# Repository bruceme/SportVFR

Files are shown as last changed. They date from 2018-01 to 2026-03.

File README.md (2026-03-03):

# SportVFR

!CATION! - Continued work in progress

An open-source DIY flight instrument

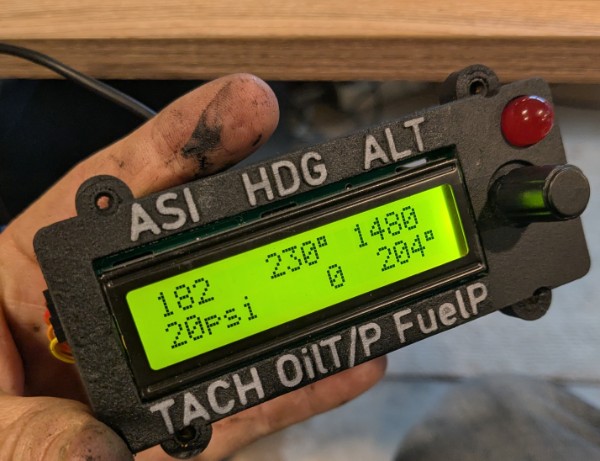
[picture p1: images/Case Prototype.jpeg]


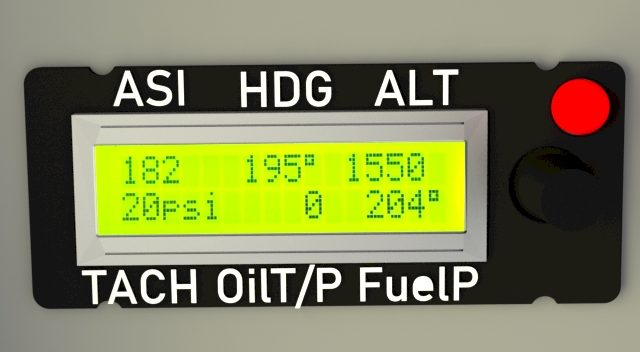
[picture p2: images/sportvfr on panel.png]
SportVFR


Early Prototype (will post updates once v2 is ready, early April 2025)

Sport VFR DIY project

# V0.3 Update (1/21/2026)
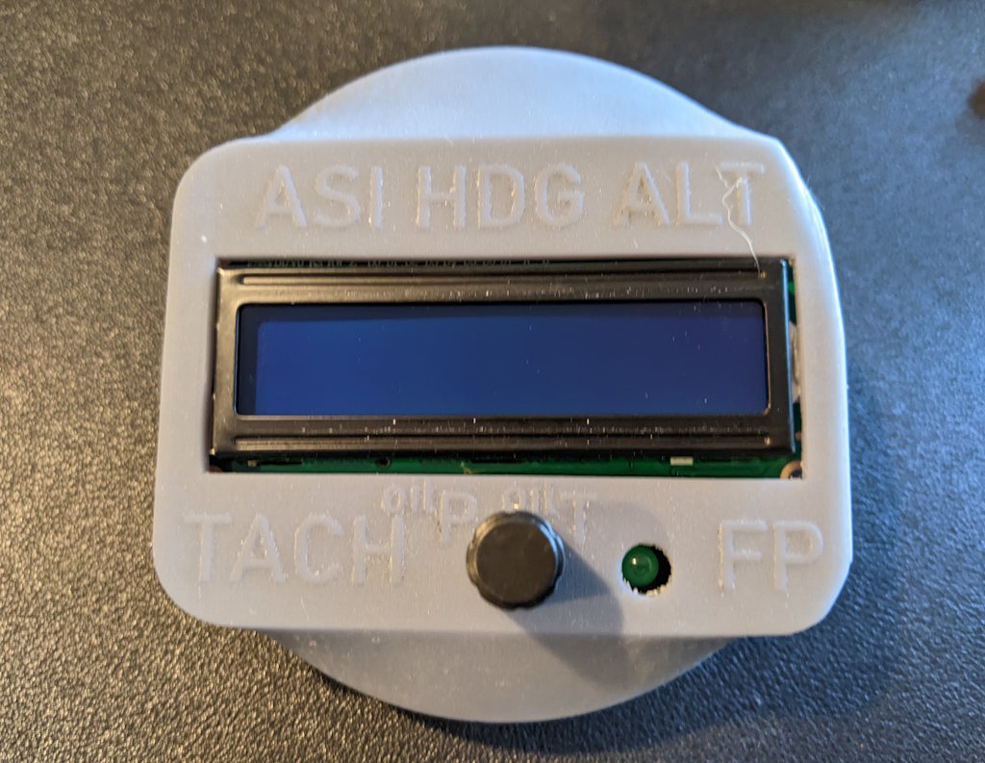
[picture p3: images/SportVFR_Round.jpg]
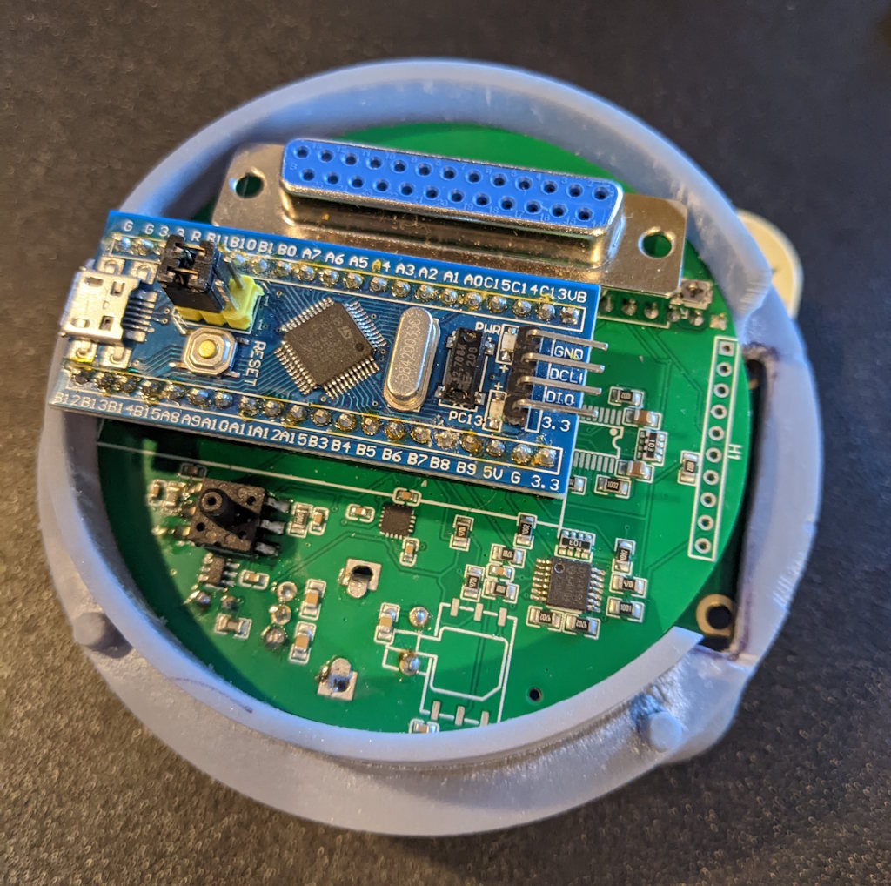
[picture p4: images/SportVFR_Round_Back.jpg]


The most obvious and immediate change is that I switched to the higher speed and higher GPIO pin count on the STM32F103 "Blue Pill".

From feedback, I built a 3-1/8" Round version of the SportVFR, it's built from the identical schematic as the rectangular version. 

I'm preparing to build a flying version, which is an engine monitor only for now.  I will add the airspeed, compass, and altimeter soon, but focusing on the engine sensors and monitoring allows me to finalize them.

I struggled with the configuration so much that I just removed it for now.  It will work for the exact engine sensors I have, if you need to tweak the coefficients for your sensors or use different kinds of sensors, you'll have to change the code for now.  I am thinking about techniques for accommodating various sensors in the hardware and software, but for now, I'm keeping it simple.

Sensors... A constant struggle.  I have settled on a few basic things around sensors.

Fuel Quantity Sensors - Low impedance resistive.  They use a precision op-amp to convert low-current/voltage signals into the analog 0-3.3v signal for the ADC.  I have 4 channels of op-amps.

Oil Temperature - I'm using the Westech oil temp sensor.  It reads 10k-Ohms at 0C, 1.6k Ohms at 39C, 212 Ohms at 100C.  This is easily a low current (0.5ma @ 120C/250F) with a simple voltage divider using a high-precision pull-up resistor.  The code interpolates the logarithmic temperature response curve to give highly accurate temperatures.

Oil Pressure / Fuel Pressure - I use 3-wire pressure sensors; they are much easier to handle and just return voltages from 0.3 - 2.7v using a 3.3v source.  Super simple, also curve-fit-interpolated by the code from measured data.

Outside Air Temp - I used a Dallas one-wire temperature probe.  It's a digital response and highly accurate from -20C - 100C.  I 3d printed a fuse-skin mounting bracket.

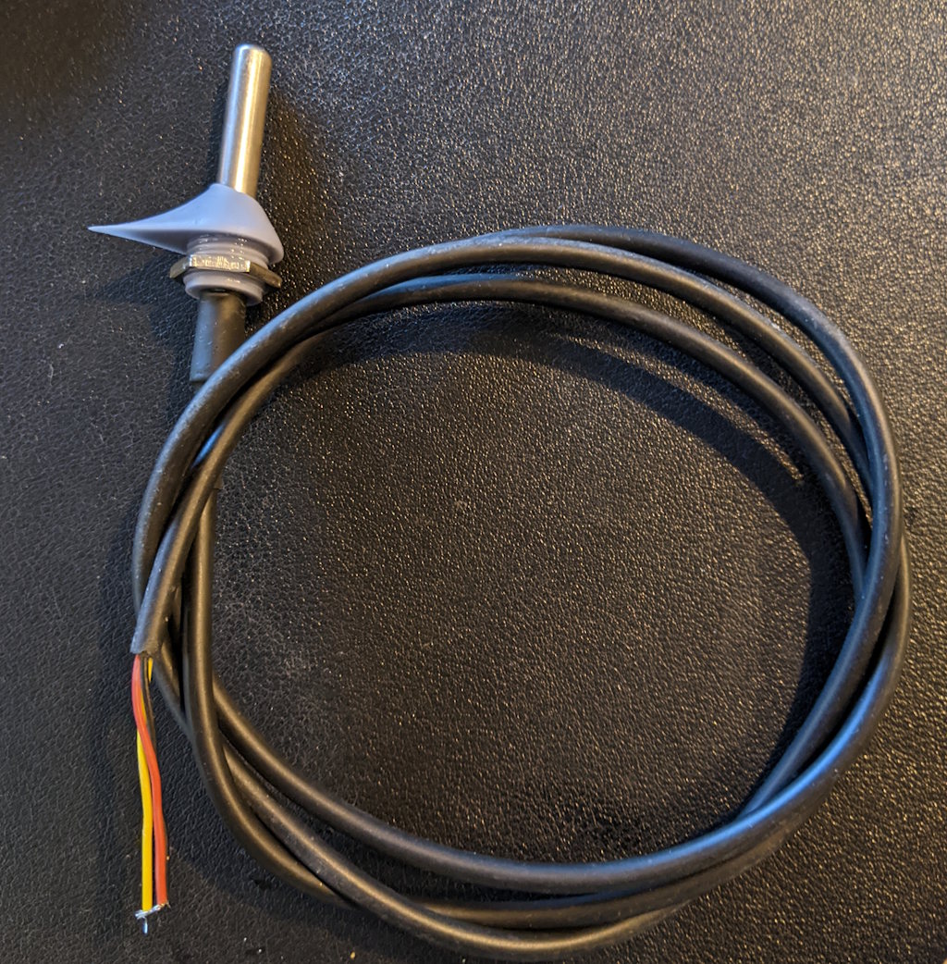
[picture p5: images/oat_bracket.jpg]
Oat Bracket


The Tachometer and Fuel Flow are both pulse count sensors.  This is best done using the built-in hardware clock timers, the code is well documented.  This is not yet tested, and I'm sure there will be tweaks as I get into real-world testing. 

# V0.2 Update (3/31/2025)

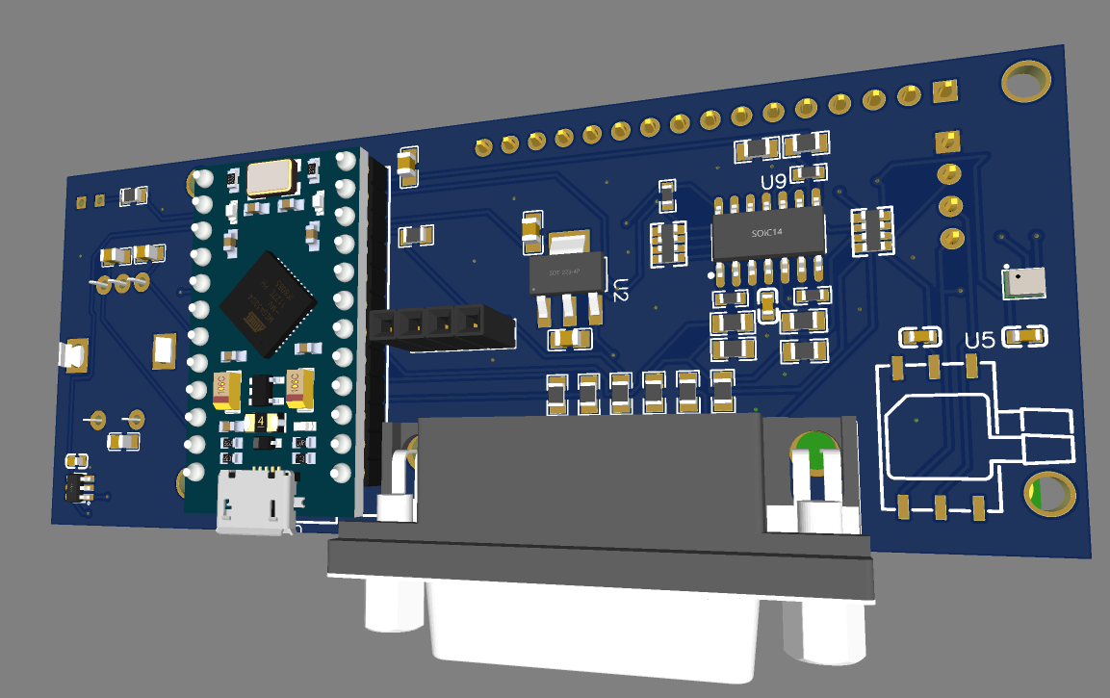
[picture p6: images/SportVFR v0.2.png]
SportVFR0_2

I've been doing a lot of work on this, and I've made several big improvements.

New Wiring Diagram
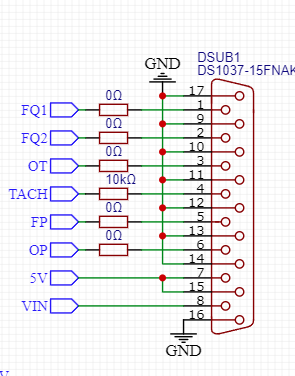
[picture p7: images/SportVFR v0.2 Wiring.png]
SportVFR_0_2_Wiring


1. There's now a DSub-15 pinout with more grounds. unfortunately, couldn't add all the 5V-Out for sensor power needed; there's just one.
1. Using op-amps to measure resistance sensors (OT, FQ1, FQ2), better all around
1. Integrated the magnetometer and absolute pressure sensors into the board design.  This lowers the project cost and makes the BOM smaller and the project simpler to build.
1. I've tested every sensor/instrument and gotten them all working
1. Code changes
 - Lots of simple fixes
 - Sensor-read-skip.  There's 7+ sensors to ready now, It's best to kkin sensor reads each cycle so the slow sensor reads update less frequently than the page display, big performance boost.
 - Created a fuel quantity page

# V0.3 Updates (tbd)

1. DSub25 with more grounds and 5v-Out for sensors
2. Aux1-5 with Aux1 pre-conditioned for low impedence sensors (another fuel quantity, etc)
3. Fuel Flow sensor added

# The Project

## Engine/Aircraft System Data Acquisition
There are only 8 analog input channels. That is limiting, but can support all required inputs;
  
| | Interface | Sensor |
|---|---|---|
| Airspeed | Serial - I2C | ABPMRRV060MG2A3 |
| Altitude | Serial - I2C | GZP6816D |
| Compass | Serial - I2C | TLV493DA1B6HTSA2 |
| Engine RPM | Counter 0-5v | Direct Messure  |
| Oil Temperature | Analog Resistive  | Low-Impedence Amp  |
| Oil Pressure | 0-5v  | 5V Pressure Gauge  |
| Fuel Pressure | 0-5v  | 5V Pressure Gauge  |
| Fuel Quantity, each tank | Analog Resistive  | Low-Impedence Amp |
| Fuel Flow 		 | Counter 0-5v  | BM8563 |
| Tach Hour Meter	 | Uses Tach and time| |

## BOM

### MCU - "Pro Micro atmega32u4"

### Compass and Altitude
  Built into the board

### Air Pressure sensors
[ABPMRRV060MG2A3](https://www.mouser.com/ProductDetail/Honeywell/ABPMRRV060MG2A3?qs=OTrKUuiFdkZ2B8eiLukmLQ%3D%3D)

*Alternatives (will require coding):*
- PX4 Airspeed Module (MS4525DO is the sensor)
- MPXV7002DP - This is a differential analog and may require amplification

### Engine Sensors

- Tach: This is a 2-pulse per rotation 12v signal coming from my Magnetos, it's voltage split to 0-5v.  You can change the number of pulses in the code.
- Oil Temp, Oil Pressure, Fuel Pressure, Fuel Quantity : These are all resistivity sensors with a typical operating range of 0-5kohm.  You can use any sensors that work on your engine.  You will need to calibrate them in the code.
  
### Display
HD44780 -I2C 1602 Character LCD Display

### Input
Rotary Encoder (CYT1100), usually comes with a small knob

### Alert LED
10mm Red LED

## Typical cost break-down (Spring 2025)

| Sport VFR | | |
| --- | --- | --- |
| | Source | Amount  |
| PCB Board | email me | $4.50  |
| Case | thingiverse | $10.00  |
| ProMicro | Jungle | $7.00 |
| Airspeed | Mouser | $35.00  |
| Rotary Encoder | Jungle | $0.56 |
| Alert LED / Resistors | Jungle | $0.10 |
| | | |
| | Sub-Total | $57.16  |
| | | |
| Sample Sensor BOM | | |
| | | |
| Oil Pressure | Jungle | $14.68  |
| Oil Temperature | Jungle | $18.55  |
| Fuel Pressure | Jungle | $23.99  |
| Fuel Quantity x2 | Jungle | $59.98  |
| | | |
| | Sub-Total | $117.20 |
| | | |
| Total. System Cost | | $174.36 |

## The build

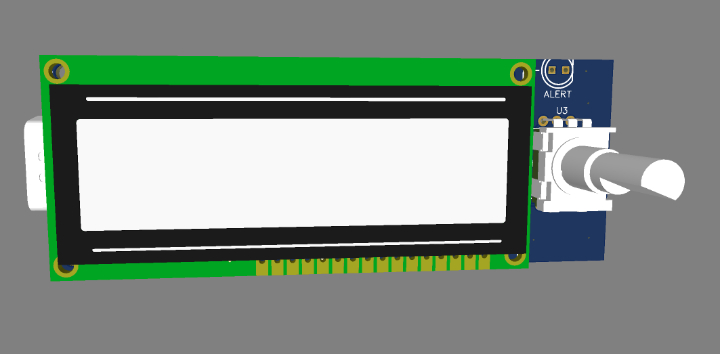
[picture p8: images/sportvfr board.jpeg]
SportVFR Board


The [SportVFR v0.2 Board](scheamtic/SportVFR.0.0.2.zip) contains the Gerber files. These can be fabricated by multiple vendors.  My run of 5 was $20 shipped.  Most components are through-hole, but some are "large" format surface mounts that can be soldered by hand with medium soldering skills.  Installing the DB-9 right-angle connector is preferred so you can remove the display quickly later to work on your panel, but you may directly solder the input wires to the through-holes.

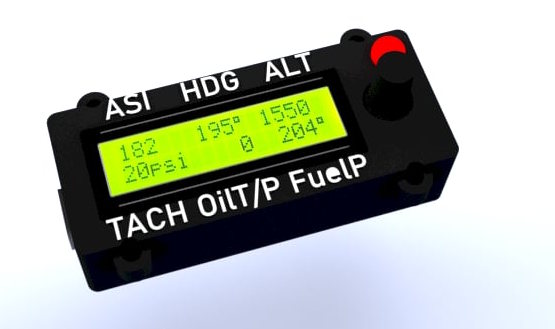
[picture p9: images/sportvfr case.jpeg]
SportVFR Board


For the case, print it yourself or send it out.  It does require 4 6x8mm "threadserts" and M3 screws to mount to the panel.

## Testing and Calibration

!CATION! - Work in progress (see updates coming soon)

Once assembled and connected to sensors you will need to calibrate the system to your sensors.  This is done by compiling to the calibration mode and recording various values at known sensor points.  Please note the calibrations are unitless, you can use whatever units you want, so long as you remember them. Typical US units would be knots, gallons, psi and Fahrenheit... But you could calibrate in kph, liters, mPa and C or any combination so long as the numbers displayed on the screen make sense to you.

Calibration points/ commands are:

You enter compass calibration mode by holding down the encoder button while powering up the unit.  From there you'll be prompted to move the plane in a circle... just follow the prompts.

NOTE: When the in-code varaibles is set to "InCalibrationMode = true" The display is outputing raw values.  The layout is similar to but not identical to the normal display mode in order to show all sensors outputs.  It as as follows:
| Airspeed | Heading  	| Altitude |	 Up/down |
| --- | --- 	| --- |---  |
| Tachometer 		| Oil Temp | Oil Press | Fuel Press | 

How to calibrate various sensors:  This calibration requires you to record values from the unconfigured device and enter them into the code.  You can always re-run these test by setting "InCongig" true and the values will get displayed.

- Airspeed: Read the zero pressure at rest.  Using a hose connected to the top tube of the airspeed sensor, have someone drive you a known speed and record that speed it to that speed.  Enter those values for AirspeedZero and Airspeed60
- Altimeter: Lookup the altitude of your current location.  Set the barometeric pressure to the closest known source and set the altitude in configuraton mode.
- Tachometer: Look up PulsesPerRPM in the code and set that to tachometer source. 
- Oil Temp: Set out a bowl of ice water and get a pot of boiling water, you'll use these test points to calibrate the temperature sensor.  Take the numbers displayed and put them into the code for OilTempMin and OilTempMax
- Oil Pressure & Fuel Pressure: Set the zero pressure at rest.  If your sensors have NPT (nation pipe thread) fittings, they will likely fit directly into a standard compressor hose.  Fill your tank to a known pressure within the range of the sensor and set it to that.  Take the numbers displayed and put them into the code as Oil/Fuel Pressure Min & Max.

# Future thoughts...

## Display or Not Display? That is the question. 

One could easily built an entire dedicated flight information display system (EFIS/ECAM) around this platform.

Or... You could say that any phone or tablet is a perfectly robust flight display system and what if you just focussed on all the data a phone/tablet can't get easily.  Airspeed, Compass, Engine, System sensors, etc.  The project needs to be integrated with a bluetooth transciever (HC-05).  Updates can easily be made to Avare for Android.  At some point compatability with other IMUs would be good so more wide adoption can be considered.

I honestly like both ideas but I lean toward the later as it's simpler and more direct.  Either way, I'd like to leave this project open-ended and not make any decisions that presuppose a display system.  

## IMU Considerations

* Sensors 
	The checked in code uses a HMC5883. The MPU9250 is newer, I would substitute.  This is a  raw output sensor and requires pretty complex 4-dof (quaternion) summing to output useful attitude data.  The altitude pressure sensor are adiquate and usually come with the attitude module.
* Cleanflight / Naze32 upgrade?
	  The Naze32 quad IMU is a nice complete inertia system with tons of great support from the quad copter community.  I have some great success setting it up in aircraft mode and interfacing via serial MultiWii protocol. It output all attitude and altitude data raw with very fast refresh.  It also supports GPS.

## AoA
    A sensitive airspeed sensor could be added for AoA and interface similarly to the airspeed

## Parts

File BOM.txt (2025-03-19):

Bill of Materials for a basic SportVFR board;  Most of these materials you can find with a quick search on the jungle store.

MCU - "Pro Micro atmega32u4"

IMU - GY-652 "10-dof IMU" consists of...
  MPU9250 - 3-Acc + 3-Gyro + 3-Mag  NOTE: Code uses HMC5883. MPU9250 is newer, I would substitute.
  BMP180  - Altimeter
  
Air Pressure sensors (Airspeed / AoA)
    ABPMRRV060MG2A3 - https://www.mouser.com/ProductDetail/Honeywell/ABPMRRV060MG2A3?qs=OTrKUuiFdkZ2B8eiLukmLQ%3D%3D
  
  Alternatives (will require re-coding): 
	PX4 Airspeed Module (MS4525DO is the sensor)
	MPXV7002DP - This is differential analog

Engine Sensors
	Tach - This is a 2-pulse per rotation 12v signal coming from my Magnetos, it's voltage split to 0-5v
	
	Oil Temp, Oil Pressure, Fuel Pressure, Fuel Quantity - These are all resistivity sensors with a typical operating range of 0-5kohm.  You can use any sensors that work on your engine.  You will need to calibrate them in the code.
  
Display - HD44780 - I2C 1602 Character LCD Display

Input - Rotary Encoder (CYT1100), usually comes with a small knob

Alert LED - 10mm Red LED

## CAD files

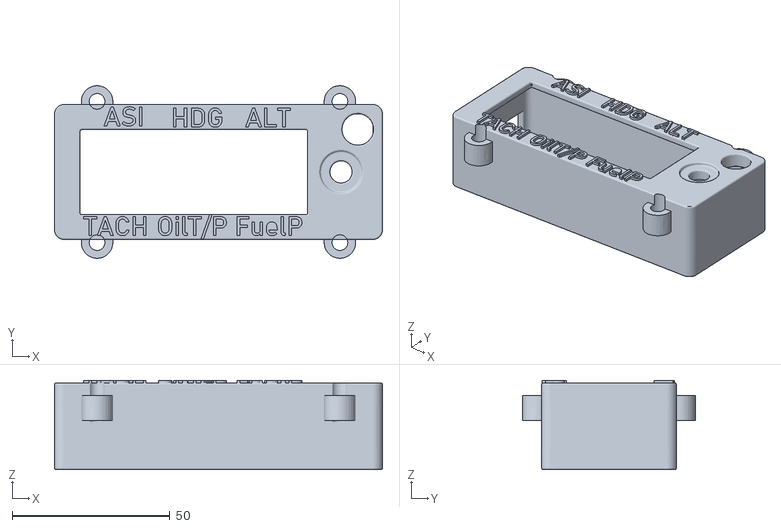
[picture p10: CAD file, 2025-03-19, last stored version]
stl/sportvfr.stl
104.0 x 54.8 x 28.3

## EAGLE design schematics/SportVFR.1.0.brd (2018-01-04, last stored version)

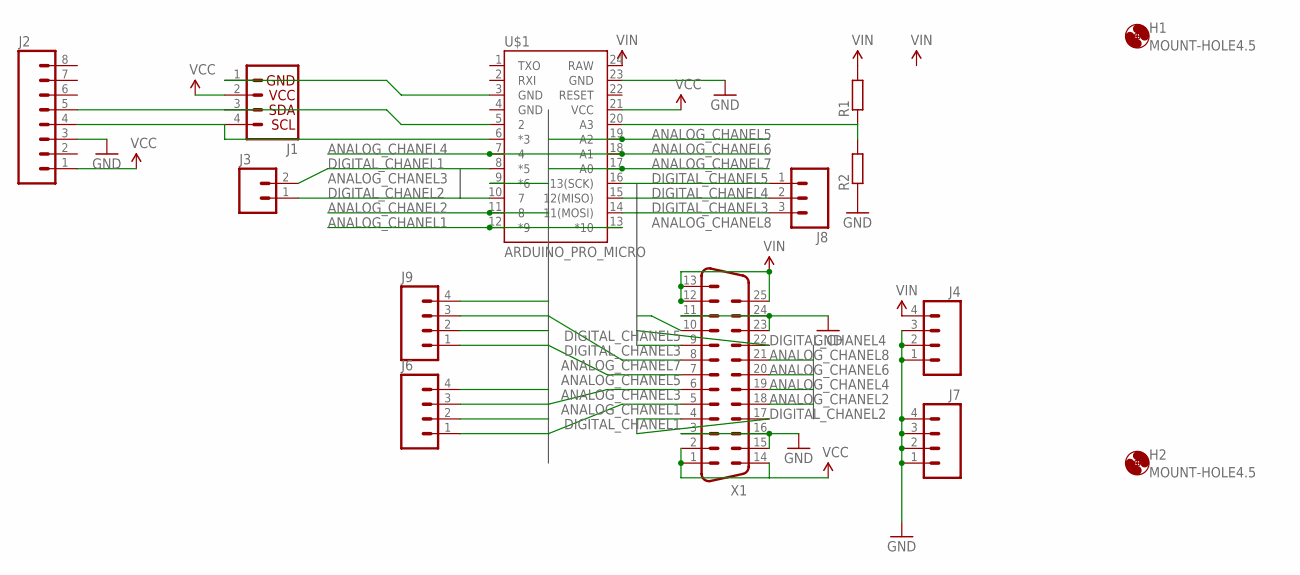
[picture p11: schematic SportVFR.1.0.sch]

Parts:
H1, H2: MOUNT-HOLE4.5; 4,5
J1: I2C_STANDARD; 1X04
J2: M08SILK_FEMALE_PTH; 1X08
J3: M02PTH; 1X02
J4, J6, J7, J9: M04PTH; 1X04
J8: M03PTH; 1X03
R1, R2: R-EU_R0805; R0805
U$1: ARDUINO_PRO_MICRO
X1: DB25HP; M25HP

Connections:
ANALOG_CHANEL1: J6.1, U$1.12 (*9), X1.5
ANALOG_CHANEL2: J6.2, U$1.11 (8), X1.18
ANALOG_CHANEL3: J6.3, U$1.9 (*6), X1.6
ANALOG_CHANEL4: J6.4, U$1.7 (4), X1.19
ANALOG_CHANEL5: J9.1, U$1.19 (A2), X1.7
ANALOG_CHANEL6: J9.2, U$1.18 (A1), X1.20
ANALOG_CHANEL7: J9.3, U$1.17 (A0), X1.8
ANALOG_CHANEL8: J9.4, U$1.13 (*10), X1.21
DIGITAL_CHANEL1: J3.2, U$1.8 (*5), X1.4
DIGITAL_CHANEL2: J3.1, U$1.10 (7), X1.17
DIGITAL_CHANEL3: J8.3, U$1.14 (11(MOSI)), X1.9
DIGITAL_CHANEL4: J8.2, U$1.15 (12(MISO)), X1.22
DIGITAL_CHANEL5: J8.1, U$1.16 (13(SCK)), X1.10
GND: J2.3, J4.1, J4.2, J4.3, J7.1, J7.2, J7.3, J7.4, R2.1, U$1.23 (GND), X1.3, X1.11, X1.15, X1.16, X1.23, X1.24
unnamed: J1.3, J2.5, U$1.5 (2)
unnamed: J1.4, J2.4, U$1.6 (*3)
unnamed: J1.1, U$1.3 (GND)
unnamed: R1.1, R2.2, U$1.20 (A3)
VCC: J1.2, J2.1, U$1.21 (VCC), X1.1, X1.2, X1.14
VIN: J4.4, R1.2, U$1.24 (RAW), X1.12, X1.13, X1.25

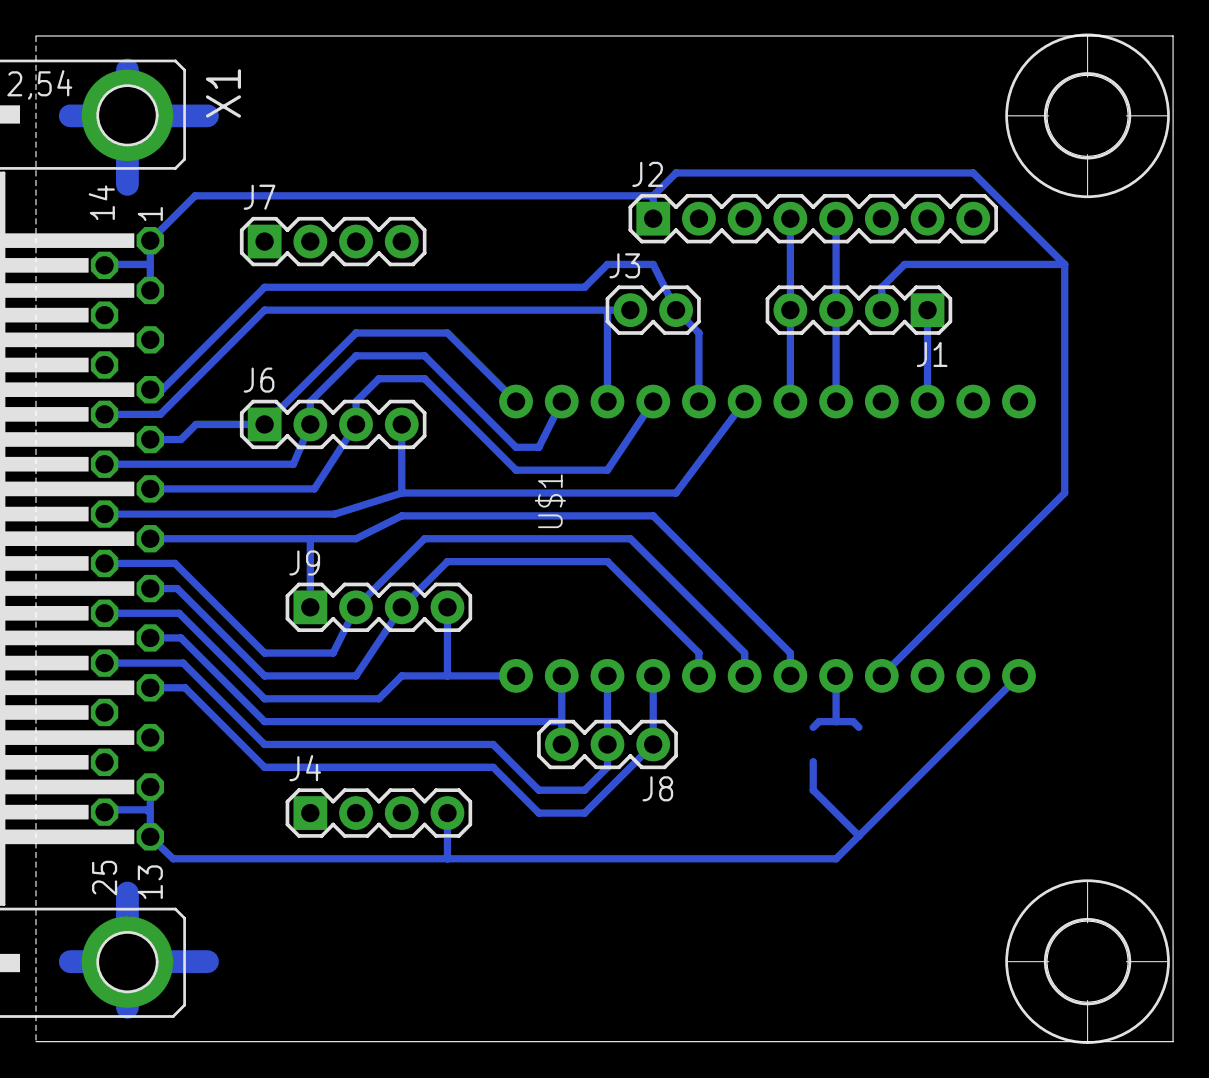
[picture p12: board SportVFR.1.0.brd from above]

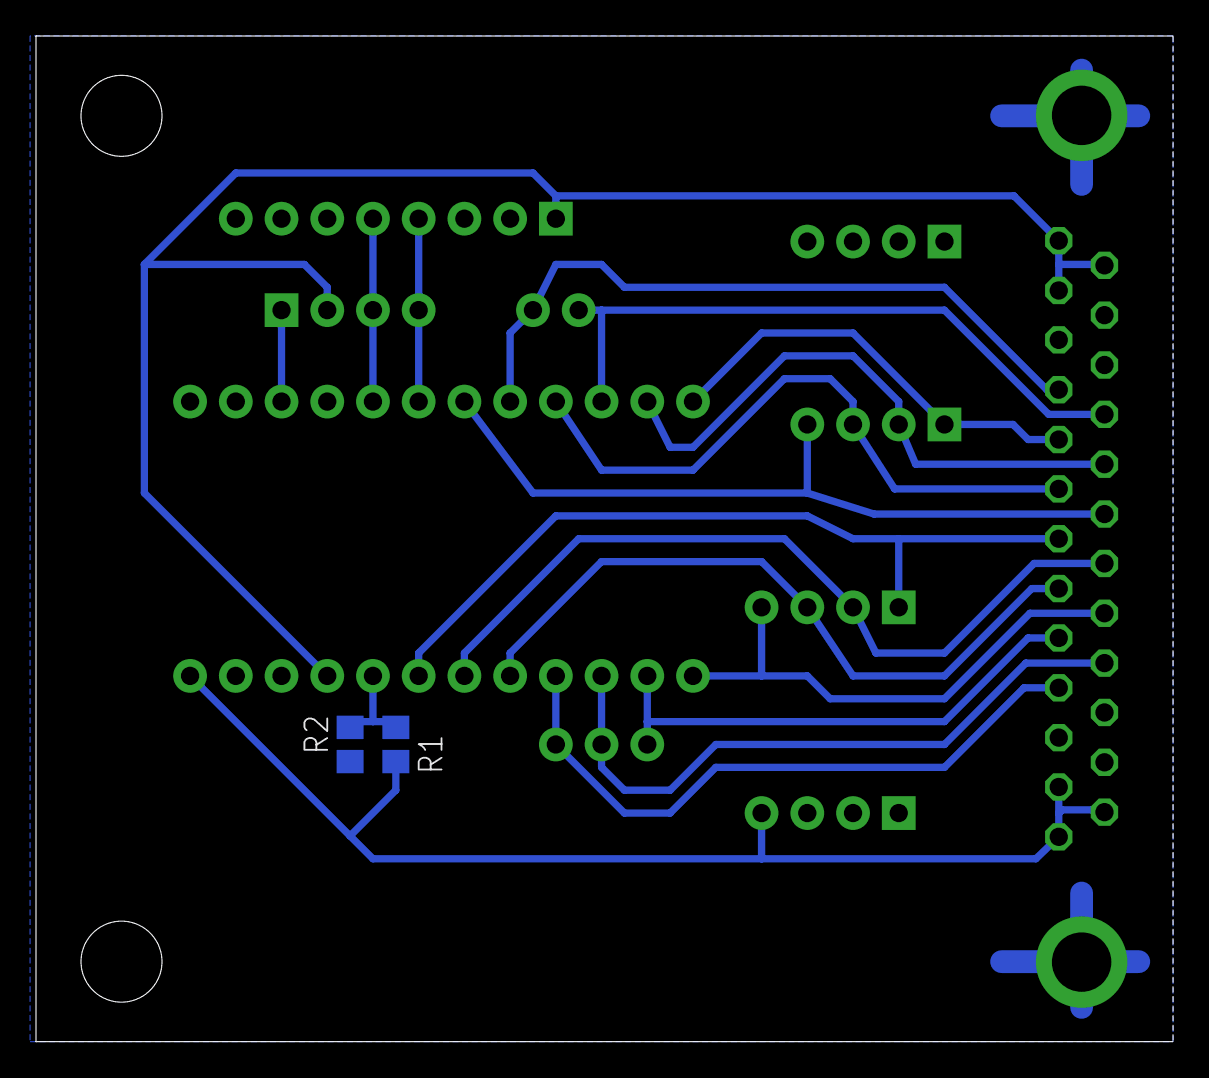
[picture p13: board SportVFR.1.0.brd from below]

Board: 2 copper layers, 63.2 x 55.9 mm, 14 parts (2 on the bottom side), 20 nets.

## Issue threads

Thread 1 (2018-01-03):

Documentation

DEKHTIARJonathan, 2018-01-03:
Hello dear friend,

I'm really interested into trying your project, do you have a listing of the sensors and devices required for the project ?
And maybe an electronic scheme for the wiring ? A few basic stuff without much details will be kinda helpful ;)

Thanks a lot,

Jonathan

bruceme, 2018-01-04:
Awesome Jonathan,

Just as a heads up, this is really a working project.  I have built a
working prototype but I haven't flown with it yet, so you'll be your own
tester.

The last known source is here...

https://github.com/bruceme/SportVFR

I committed the schematics and BOM just now, pull the latest and have at it.

-Bruce

On Wed, Jan 3, 2018 at 2:50 PM, Jonathan DEKHTIAR <notifications@github.com>
wrote:

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

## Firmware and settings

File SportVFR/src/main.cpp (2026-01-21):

/*-----( Import needed libraries )-----*/
// Get the LCD I2C Library here:
#include <LiquidCrystal_I2C.h>
LiquidCrystal_I2C lcd(0x27, 16, 2); // set the LCD address to 0x27 for a 16 chars and 2 line display

#include <ezButton.h>
ezButton button(6); // 6 on the PCB

String Error = ""; // Error message

#include <EEPROM.h>
#include <SimpleKalmanFilter.h>

#define deltaAltVSI 100

#define BARROW_EEPROP_OFFSET 240

#define MIN_OilTemp 95
#define MAX_OilTemp 245
#define MIN_OilPress 25
#define MAX_OilPress 100
#define MIN_FuelPress 1
#define MAX_FuelPress 8
#define MIN_FuelQuantity 30 // 3.0g
#define ALARM_PIN 8         // On 8 on the PCB

#include "Mapped/MappedADC.hpp"
#include "Mapped/MappedAirspeed.hpp"

MappedAirspeed airspeed(0); // pressure sensor
MappedADC oilPres(A1, 1);
MappedADC oilTemp(A0, 2);
MappedADC fuelPres(A2, 3);
MappedADC fuelQ1(10, 4);
MappedADC fuelQ2(9, 5);
// Mapped auxInput(A3,5); // optional

int heading = 360;
int altitude = 0;
char vsi = '^';
int tachometer = 0;
int lastmillis = millis();
byte revolutions = 0;
int altitudeLast;
bool powerOn = true;
int barrow;
bool up;
bool down;
unsigned long now;
const int sensorCalibration = 3031 - 3034;         // current reference barrometeric pressure - pressure you read when you set your altitude
const int barrowOffset = 2992 + sensorCalibration; // standard + offset for sensor calibration

#define FeetPerMeter 3.28084
#define MPaPerBarrow_256 8669L // barrow is 100 * InHq this 256 bigger than it needs to be (simple math)

#include "configuration.hpp"
#include "encoder.hpp"
#include "utility.hpp"

#include "instruments/altimeter.hpp"
#include "instruments/tach.hpp"
#include "instruments/compass.hpp"

int blinker = 0;

#define EnginePage 0
#define FuelPage 1
#define PageCount 2
int page = EnginePage;

// Use this to display raw sensor output for configuration
// #define SENSOR_CONFIG
int fq1, fq2;
int curDeltaTPhase = 0;

void NormalDisplay()
{
  now = millis();
  auto deltaT = (int)(now - lastmillis);
  auto deltaTPhase = deltaT / 100;
  if (curDeltaTPhase != deltaTPhase)
  {
    curDeltaTPhase = deltaTPhase;
    switch (deltaTPhase)
    {
    case 0:
//      Serial.print('0' + deltaPhase);
      tachometer = ReadTachometer();
      // heading = ReadCompass();
      altitude = GetAltitude();
      break;
    case 1:
//      Serial.print('0' + deltaPhase);
      airspeed.Read();
      oilTemp.Read();
      oilPres.Read();
      fuelPres.Read();
      break;
    case 2:
//      Serial.print('0' + deltaPhase);
      fq1 = fuelQ1.Read();
      fq1 = fq1 < 0 ? 0 : fq1;
      fq2 = fuelQ2.Read();
      fq2 = fq2 < 0 ? 0 : fq2;
      auto fp = fuelPres.QuickRead();
      auto ot = oilTemp.QuickRead();
      auto op = oilPres.QuickRead();

      auto alarmT = (ot > MAX_OilTemp ||
                     ot < MIN_OilTemp ||
                     op > MAX_OilPress ||
                     op < MIN_OilPress ||
                     fp > MAX_FuelPress ||
                     fp < MIN_FuelPress ||
                     fq1 < MIN_FuelQuantity ||
                     fq2 < MIN_FuelQuantity) &&
                    blinker > 1;

      blinker = (blinker + 1) % 4;

      digitalWrite(ALARM_PIN, alarmT ? HIGH : LOW);
      break;
    }
  }
  if (deltaT > 300)
    lastmillis = now;

#ifdef SENSOR_CONFIG
  {
    lcd.setCursor(0, 0);                           // go to the next line
    lcd.print(Format(airspeed.RawRead(), 3, ' ')); // 3
    lcd.print(' ');
    lcd.print(Format(fuelQ1.RawRead(), 3, '0')); // 3
    lcd.print(' ');
    lcd.print(Format(fuelQ2.RawRead(), 3, '0')); // 3
    lcd.print(' ');
    lcd.print(Format(altitude, 4, ' ')); // 15

    lcd.setCursor(0, 1); // go to the next line
    lcd.print("   ");
    lcd.print(Format(oilTemp.RawRead(), 3, '0')); // 8
    lcd.print(' ');
    lcd.print(Format(oilPres.RawRead(), 3, '0')); // 13
    lcd.print(' ');
    lcd.print(Format(fuelPres.RawRead(), 3, '0')); // 16
    return;
  }
#endif

#ifdef SHOW_RAW_COMPASS
  lcd.setCursor(0, 0);
  ShowRawCompass();
  return;
#endif

  lcd.setCursor(0, 0);                                 // go to the next line
  lcd.print(Format(airspeed.QuickRead(), 3, ' '));     // 3
  lcd.print("   ");                                    // 6
  lcd.print(Format(heading - heading % 5, 3, '0'));    // 9
  lcd.print((char)0xdf);                               // 10
  lcd.print(Format(altitude - altitude % 10, 5, ' ')); // 15
  lcd.write(vsi);                                      // 16

  lcd.setCursor(0, 1); // go to the next line
  if (page == EnginePage)
  {
    lcd.print(Format(tachometer, 4, '0'));           // 4
    lcd.print(' ');                                  // 5
    lcd.print(Format(oilTemp.QuickRead(), 3, ' '));  // 8
    lcd.print((char)0xdf);                           // 9 deg
    lcd.print(Format(oilPres.QuickRead(), 4, ' '));  // 13
    lcd.print(Format(fuelPres.QuickRead(), 3, ' ')); // 16
  }
  else if (page == FuelPage)
  {
    lcd.print(Format(fq1 / 10, 2, ' ')); // 2
    lcd.print('.');                      // 3
    lcd.print(Format(fq1 % 10, 1, '0')); // 4
    lcd.print('g');                      // 5
    lcd.print("<fuel>");                 // 11
    lcd.print(Format(fq2 / 10, 2, ' ')); // 13
    lcd.print('.');                      // 14
    lcd.print(Format(fq2 % 10, 1, '0')); // 15
    lcd.print('g');                      // 16

    lcd.print(Format(oilTemp.QuickRead(), 3, ' '));  // 8
    lcd.print((char)0xdf);                           // 9 deg
    lcd.print(Format(oilPres.QuickRead(), 4, ' '));  // 13
    lcd.print(Format(fuelPres.QuickRead(), 3, ' ')); // 16
  }
}
bool inError = false;
void setup()
{
  Serial.begin(9600);

  // Serial is being used for it's interupts :(
  attachTachInt();

  EEPROM.get(BARROW_EEPROP_OFFSET, barrow);
  if (barrow < 2800)
    barrow = 2992;

  // airspeed.Initialize();
//  InitAltimeter();
//  InitCompass();

  lcd.begin(16, 2); // initialize the lcd for 20 chars 4 lines and turn on backlight
  lcd.backlight();
  // SetupLCDCustomCharacters();

  //  encoder.write(barrow*4);

//  pinMode(ALARM_PIN, OUTPUT);

  // InitializeEncoder();

  // CalibrationReset();
  // inError = Error.length() > 0;
  // lcd.clear();
  // lcd.setCursor(6,0);
  // lcd.print("SportVFR");
  // delay(500);
  // Serial.println("Hello");
}

/*--(end setup )---*/

void loop()
{
  button.loop();
  int buttsUp = button.isReleased();

  if (inError)
  {
    lcd.setCursor(0, 0);
    lcd.print(Error.c_str());
    inError = !buttsUp;
    return;
  }

  if (inSetBarrowMode)
  {
    barrow = encoder / 7;

    lcd.setCursor(0, 0); // go to the next line
    lcd.print("Set Pressure Alt");
    lcd.setCursor(0, 1);                     // go to the next line
    lcd.print(Format(barrow / 100, 2, ' ')); // 2
    lcd.print('.');                          // 3
    lcd.print(Format(barrow % 100, 2, '0')); // 5
    lcd.print("      ");
    lcd.print(Format(altitude, 5, ' ')); // 16

    if (buttsUp && inSetBarrowMode)
    {
      inSetBarrowMode = false;
      lcd.clear();
      EEPROM.put(BARROW_EEPROP_OFFSET, barrow);
      encoder = EnginePage;
      return;
    }
    inSetBarrowMode = true;
    altitude = GetAltitude();
  }

  // Detect setup mode select on boot
  if (buttsUp)
  {
    if (powerOn)
      inConfigMode = true;
    else
    {
      inSetBarrowMode = true;
      encoder = barrow * 7;
    }

    powerOn = false;
  }

  if (!inSetBarrowMode)
    NormalDisplay();

  page = (encoder / 4 + PageCount) % PageCount;

  delay(10);
} /* --(end main loop )-- */

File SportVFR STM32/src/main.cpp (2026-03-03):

#include <Arduino.h>
#include <Wire.h>
#include <LiquidCrystal.h>
#include <EEPROM.h>
#include <SimpleKalmanFilter.h>
#include "Adafruit_MCP3421.h"

#include "platform/stm32f103.hpp"
#include "instruments/temperature.hpp"
#include "sensors.hpp"
#include "header.hpp"
#include "encoder.hpp"

// Display Variables
// RS, E, D4, D5, D6, D7
LiquidCrystal lcd(LCD_RS_PIN, LCD_EN_PIN, LCD_D4_PIN, LCD_D5_PIN, LCD_D6_PIN, LCD_D7_PIN);

Adafruit_MCP3421 altitudeADC;

/// @brief Display the current page and handle navigation between pages
/// @note Each page function handler can return DISP_OK to stay on the page, or DISP_RETURN to go back to the main page
void Display()
{
  // Refresh our sensors
  PollAllSensors();

  // if (page < 0 || page >= PageCount)
  //   page = Page0;

  // Do the page display navigation
  auto dispResult = PageDisplayLookup[page]();

  if (encoder < 0)
    encoder = 2;

  if (page != RawDisplayPage)
    page = 1 + (encoder/2 % 2); 
}

bool isButtonPressed();

/////////////////////// ---------- S  E  T  U  P ---------- ///////////////////////
void setup()
{
  //Serial.begin(9600);
  pinMode(ALARM_PIN, OUTPUT); 
  pinMode(BUTTON_PIN, INPUT_PULLUP);  // Use pull-up resistor
  analogReadResolution(12);  // 12 bit ADC

  // Remap I2C1 to PB8 (SCL) and PB9 (SDA)
  Wire.setSCL(PB6);
  Wire.setSDA(PB7);
  Wire.begin();

  delay(50);
  // Move to altimeter.hpp
  byte count = 10;
  while (count -- > 0 && !altitudeADC.begin()) {
    Serial.println("Failed to find MCP3421 chip");
    delay(10); // Avoid a busy-wait loop
  }
  if (altitudeADC.isReady())
  {
    altitudeADC.setGain(GAIN_8X);
    altitudeADC.setResolution(RESOLUTION_12_BIT); // 240 SPS (12-bit)
    altitudeADC.setMode(MODE_CONTINUOUS);
  }

  EEPROM.get(BARROW_EEPROP_OFFSET, barrow);
  EEPROM.get(BARROW_CALIB_EEPROP_OFFSET, barrowOffset);
  if (barrow < 2800)
    barrow = 2992;

  setupEncoders();
  setupOAT();
  setupFuelFlowCapture();
  setupTachCapture();

  lcd.begin(16, 2); // initialize the lcd for 20 chars 4 lines and turn on backlight

  page = isButtonPressed() ? RawDisplayPage : EnginePage;
}


int blinker = 0;
bool blinkOff = false;

/////////////////////// ---------- L O O P  ---------- ///////////////////////
void loop()
{
  buttUp = buttonReleased();
  // if (inError)
  // {
  //   lcd.setCursor(0, 1);
  //   lcd.print(Error.c_str());
  //   inError = !buttUp;
  //   return;
  // }

  if (inError)
  {
    if (blinker++ == 50)
    {
      digitalWrite(ALARM_PIN, HIGH);
      blinkOff = true;
    }
    else if (blinker > 100)
    {
      digitalWrite(ALARM_PIN, LOW);
      blinkOff = true;
      blinker = 0;
    }
  }


  Display();

  delay(10);
} /* --(end main loop )-- */

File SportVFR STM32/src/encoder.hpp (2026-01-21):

// //                           _______         _______       
// //           A    Pin1 ______|       |_______|       |______ Pin1
// // negative <---         _______         _______         __      --> positive
// //           B    Pin2 __|       |_______|       |_______|   Pin2


// byte a=1,b=1;
// volatile int encoder = 0;

// #define EncoderPinA PA8   // 0 on the PCB
// #define EncoderPinB PA9   // 1 on the PCB

// void A_Change()
// {
//   a = digitalRead(EncoderPinA);
//   if (a ^ b)
//     encoder--;

//   if (!a ^ b)
//     encoder++;
// }
// void B_Change()
// {
//   b = digitalRead(EncoderPinB);
//   if (a ^ !b)
//     encoder--;
//   if (a ^ b)
//     encoder++;
// }

// void InitializeEncoder()
// {
//     pinMode(EncoderPinA, INPUT_PULLUP);
//     pinMode(EncoderPinB, INPUT_PULLUP);
//     attachInterrupt(digitalPinToInterrupt(EncoderPinA),A_Change,CHANGE);
//     attachInterrupt(digitalPinToInterrupt(EncoderPinB),B_Change,CHANGE);
// }
#pragma once

#include <Arduino.h>

#define ENCODER_PIN_A PA8
#define ENCODER_PIN_B PA9


volatile int32_t encoder = 0;
volatile bool lastA = 0;

void handleEncoder() {

  bool A = digitalRead(ENCODER_PIN_A);
  bool B = digitalRead(ENCODER_PIN_B);

  if (A != lastA) {
    if (A == B) {
      encoder++;
    } else {
      encoder--;
    }
    lastA = A;
  }
}

#define BUTTON_PIN PA10  // Replace with your button pin
#define DEBOUNCE_MS 50  // Debounce time in milliseconds

volatile bool buttonPressed = false;
volatile uint32_t lastInterruptTime = 0;

bool isButtonPressed()
{
  return digitalRead(BUTTON_PIN) == LOW;
}

bool buttonReleased() {
  auto buttSav = buttonPressed;
  buttonPressed = false;
  return buttSav;
}

void handleButtonInterrupt() {
  uint32_t currentTime = millis();
  if (currentTime - lastInterruptTime > DEBOUNCE_MS) {
    buttonPressed = isButtonPressed();
    lastInterruptTime = currentTime;
  }
}

void setupEncoders()
{
  pinMode(ENCODER_PIN_A, INPUT_PULLUP); // Channel A (CLK)
  pinMode(ENCODER_PIN_B, INPUT_PULLUP); // Channel B (DT)

  // Enable AFIO clock and remap EXTI for PA8
  AFIO->EXTICR[2] &= ~(AFIO_EXTICR3_EXTI8); // Clear EXTI8 bits
  AFIO->EXTICR[2] |= AFIO_EXTICR3_EXTI8_PA; // Map EXTI8 to PA8

  attachInterrupt(digitalPinToInterrupt(ENCODER_PIN_A), handleEncoder, CHANGE);

  pinMode(BUTTON_PIN, INPUT_PULLUP);  // Use pull-up resistor
  attachInterrupt(digitalPinToInterrupt(BUTTON_PIN), handleButtonInterrupt, FALLING);
}

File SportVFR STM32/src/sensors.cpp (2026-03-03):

#include <Arduino.h>
#include "header.hpp"
#include "sensors.hpp"

AlarmState SensorBoundsCheck(AlarmState alarm, sensor *s)
{
  if (alarm != NONE)
    return alarm;

  if (s->lastValue >= s->alarmHigh)
    return HIGH_ALARM;
  if (s->lastValue >= s->warnHigh)
    return HIGH_WARNING;
  if (s->lastValue <= s->alarmLow)
    return LOW_ALARM;
  if (s->lastValue <= s->warnLow)
    return LOW_WARNING;

  return NONE;
}

// Fuel Quantity is a linear interpolation of the 8 points in the multiPoint struct, 
// which are populated from the fuel map calibration.  This is manual today, but 
// eventually we can add a calibration routine that will populate the multiPoint 
// struct from user input.
short MapADCToOutput(multiPoint *mp, short adcValue)
{
    auto Range = mp->Range;
    auto Domain = mp->Domain;
    auto inT = adcValue;

    // find the range
    byte i;
    for (i = 0; i < 7; i++)
    {
        if (adcValue < Range[i + 1])
            break;
    }

    // linear interpolate
    int outT = (int)Domain[i];
    if (i < 7)
    {
        outT += (int)((long)(Domain[i + 1] - Domain[i]) * (long)(inT - Range[i]) / (long)(Range[i + 1] - Range[i]));
    }
    return (short)outT;
}

sensor OilPressure = {"OP", OP_PIN, MAX_INT, MIN_OilPress + 10, MAX_INT, MIN_OilPress, 2, '0',
/// @Derivation
///  AskAI: The following measured voltages I'd like to map into 12-bit adc values then 
///         curve fit a function that will convert the adc readAnalog value into a pressure. 
///         Output a function in 10ths of PSI using only integer math.
///         (0psi,0.38v),(40,1.19),(50,1.4),(60,1.74),(70,2.02),(80,2.08),(90,2.55)
    [](sensor *thisSensor) {
        long x = (long)analogRead(thisSensor->pin);

        int psi = (int)(((x << 16) / 1840000) - (((x * x)<<7) / 94336000)) - 8;
    
        thisSensor->lastValue = (psi < 15) ? 0 : psi;

         return NONE;
     }};

#include <stdint.h>

// Fixed constants
#define R_FIXED     672        // ohms
#define LN_A_Q15    226000     // ln(17200) * 10000
#define B_Q15       181        // 0.0181 * 10000

// Fast integer log2 approximation
static int32_t fast_log2_q15(uint32_t x)
{
    int n = 31 - __builtin_clz(x);   // integer part
    x <<= (31 - n);                  // normalize to 1.xxx in Q31

    // fractional approximation: y = x/2^31
    // log2(y) ≈ (y - 1) * 1.4427
    int32_t frac = (int32_t)(x >> 16) - 32768;   // Q15
    int32_t frac_scaled = (frac * 47321) >> 15;  // 1.4427 in Q15

    return (n << 15) + frac_scaled;  // Q15 log2(x)
}

// // Convert ADC → temperature in °C using integer math
// int thermistor_temp_c_int(uint16_t adc)
// {
//     // Compute resistance in ohms (integer)
//     uint32_t r = (uint32_t)R_FIXED * adc / (4095 - adc);

//     // ln(R) = log2(R) * ln(2)
//     int32_t log2_r_q15 = fast_log2_q15(r);
//     int32_t ln_r_q15 = (log2_r_q15 * 22713) >> 15;  // ln(2)=0.693147 in Q15

//     // T_F = (ln(A) - ln(R)) / B
//     int32_t num = LN_A_Q15 - ln_r_q15;  // still Q15
//     int32_t t_f_q15 = (num * 10000) / B_Q15;

//     // Convert °F → °C
//     int t_f = (int)(t_f_q15 / 10000);
//     auto t_c = (t_f - 32) * 5 / 9;

//     return t_c;
// }

//34 °F	0x2B3	691
//60 °F	0x351	849
//90 °F	0x4C1	1217
//190 °F	0xB80	2944

#include <math.h>
#include <stdint.h>

// int thermistor_temp_c_int(uint32_t adc)
// {
//   return 93.9477 * log(adc) + 0.008935 * adc - 580.804;
// }

/**
 * Integer-only approximation for y = 11720.36 + (-593.2308 - 11720.36)/(1 + (x/46955250000)^0.162156)
 * Range: 700 <= adc <= 3500
 * Accuracy: ~ +/- 1.0 (Well within the requested +/- 2)
 */
int thermistor_temp_c_int(uint32_t adc){
    if (adc == 0) return -32768; // Handle log(0) error
    
    // 1. log2(adc) scaled by 1024
    uint32_t x = (uint32_t)adc;
    int32_t msb = 31 - __builtin_clz(x);
    int32_t fractional = ((x ^ (1 << msb)) << 10) >> msb;
    int32_t log2_scaled = (msb << 10) + fractional;

    // 2. Map to original coefficients
    // y = (93.9477 * ln(2)) * log2(x) + 0.008935 * x - 580.804
    //   = 65.11933 * log2(x) + 0.008935 * x - 580.804
    
    // We use a high scaling factor (2^30) to preserve precision
    // log2_scaled is already 2^10, so log_coeff is 2^20
    int64_t term_log  = (int64_t)68282054 * log2_scaled; // 65.11933 * 2^20 * 2^10
    int64_t term_lin  = (int64_t)9593257 * x;            // 0.008935 * 2^30
    int64_t term_cons = (int64_t)623636096000;           // 580.804 * 2^30

    // Sum and shift back to 1:1 scale (2^30)
    int32_t result = (int32_t)((term_log + term_lin - term_cons) >> 30);

    return (short)result;
}

// pin, warnHigh, warnLow, alarmHigh, alarmLow, lastValue, readCore
sensor OilTemperature = {"OT", OT_PIN, MAX_OilTemp - 10, MIN_OilTemp + 10, MAX_OilTemp, MIN_OilTemp, 3, '0',
    [](sensor *thisSensor) {
        thisSensor->lastValue = thermistor_temp_c_int(analogRead(thisSensor->pin));
        return (thisSensor->lastValue < 0) ? DATA_MISSING_ALARM : NONE;       
     }};


sensor FuelPressure = {"FP", FP_PIN, MAX_INT, MIN_FuelPress + 10, MAX_INT, MIN_FuelPress, 3,'0',
    /// @Derivation
    ///  AskAI: The following measured voltages I'd like to map into 12-bit adc values then 
    ///         curve fit a function that will convert the adc readAnalog value into a pressure. 
    ///         Output a function in 10ths of PSI using only integer math.
    ///         (0psi, 0.37v),(15,0.9),(20,1.84),(25,1.92),(30,2.41)
    [](sensor *thisSensor) {
        long x = analogRead(thisSensor->pin);

        // y = -96.26 + 0.2071*x - 0.00002242*x^2
        // 316579 = 2^16 / 0.2071
        // 5709000 = 2^7 / 0.000022420
        float p_tenths = ((x<<16)/316579) - (((x * x)<<7)/5709000) - 96;

        thisSensor->lastValue = (p_tenths < 5) ? 0 : p_tenths;

        return NONE;
     }};


multiPoint fuelQ1mp = {
    .Range = {0, 512, 1024, 1536, 2048, 2560, 3072, 4095},
    .Domain = {0, 21, 43, 64, 86, 107, 129, 150}
};
multiPoint fuelQ2mp = {
    .Range = {0, 512, 1024, 1536, 2048, 2560, 3072, 4095},
    .Domain = {0, 21, 43, 64, 86, 107, 129, 150}
};

sensor FuelQuantity1 = {"<Fuel", FQ1_PIN, MAX_INT, MIN_FuelQuantity+2, MAX_INT, MIN_FuelQuantity,4,'0',
    [](sensor *thisSensor) {
         auto adcValue = analogRead(thisSensor->pin);
         thisSensor->lastValue = MapADCToOutput(&fuelQ1mp, adcValue);
         return NONE;
     }};

sensor FuelQuantity2 = {"Fuel>", FQ2_PIN, MAX_INT, MIN_FuelQuantity+2, MAX_INT, MIN_FuelQuantity,4,'0',
    [](sensor *thisSensor) {
         auto adcValue = analogRead(thisSensor->pin);
         thisSensor->lastValue = MapADCToOutput(&fuelQ2mp, adcValue);
         return NONE;
     }};


uint32_t GetFuelFlowDLPH();

sensor FuelFlow = {"FF", -1, MAX_INT, -MAX_INT, MAX_INT, -MAX_INT, 3,'0',
    [](sensor *thisSensor) {
         thisSensor->lastValue = GetFuelFlowDLPH(); // Replace with actual fuel flow reading
         return NONE;
     }};
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

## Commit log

2018-01-04 added schematics
    [SportVFR.1.0.brd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]
2018-01-04 Added Bom
2025-03-19 Added images and tweaked content
    [sportvfr.stl]
2025-03-19 First case prorotype photo
    [sportvfr.stl]
2025-03-24 Cleaned up instruments and added support for ADP sensor
2025-03-31 Updated sensors, better modes, added amps, lots of pins
    [SportVFR.1.0.brd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]
2026-01-21 Revise README with V0.3 update and project status
    Updated project status and detailed V0.3 changes regarding hardware and sensor configurations.
2026-01-21 oat and bracket

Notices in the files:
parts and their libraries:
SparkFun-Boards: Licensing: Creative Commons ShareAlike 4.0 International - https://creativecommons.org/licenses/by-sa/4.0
